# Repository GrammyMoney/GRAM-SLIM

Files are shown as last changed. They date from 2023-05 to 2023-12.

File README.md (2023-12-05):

# GRAM Slim

# Introduction 
**GRAM Slim** is a modular low-profile 21-button controller designed for Smash and FGC games. It has the standard pinout for firmwares like HayBox and Pico-Rectangle, and is also compatible with more fleshed-out FGC firmwares like GP2040-CE. With industrial design from GRAM, and PCB designed in collaboration with Quark.Works, this guide goes over a DIY-friendly approach to building the original GRAM Slim, and future guides/repos may hold remixes and modifications.

**If you would like to support the developer of this project, consider purchasing parts like buttons, PCBs, USB-C to GCC cables, and official GRAM builds at [GRAMCTRL.COM](https://www.gramctrl.com) rather than a fab house.**



Included Files
-
Included in this repo is all the files needed to get started with a simple GRAM Slim build:
- **GRAM Slim Frame .stl files**
- **Fab files for top and bottom panels**
- **Template DXF** for customizing top and bottom panels
- **GRAM 24mm keycap button .stl files**

Additional Information
-
If you want more info around GRAM builds, both open source and official builds, please join the [GRAM Digital Controllers Discord](https://discord.gg/6TuHw2r2X4) to ask questions and work with the community! I would love to see people creating new interesting designs, and building upon the initial framework.

Thanks & Acknowledgements
-
There are several people who made this project possible, either directly or indirectly.
- [Quark](https://twitter.com/quark_works), who did the PCB design on this and many other GRAM projects.
- [Bjart](https://twitter.com/bjartskular2), who developed the OFOF1 chassis, which was the initial development for a lot of the ideas explored in this build, including using PCB fabs for the panels, and the general idea of stacking two panels on a frame for the enclosure.
- My life and business partner [BRUISES](https://twitter.com/bruisesxo), who has turned GRAM into what it is today, and had incredible patience with me as I toiled away at my computer late into the night designing this thing.

# Ordering & Customization Guide
While most of these files are universal and can be used at any fab house, **JLCPCB** has become the de-facto standard for DIY box manufacturing. This is due to their hyper-affordable pricing and low minimum order quantity.

Bill of Materials
-
Per GRAM Slim, you will need (some files can be made using this repository, but I will link to places to purchase them if you would like to avoid MOQs)
- 1 x [GRAM Slim PCB](https://gramctrl.com/products/gram-slim-pcb)
- 1 x set of [Top/Bottom panels](https://gramctrl.com/products/gram-slim-aluminum-panels)
- 21 x [Kailh Choc V1 switches](https://www.moergo.com/products/kailh-choc-v1-key-switches-red-brown-white-pro-red-20-pack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) (Red, Red Pro, and Whites are all great choices)
- 21 x [PG1350 Hotswap Sockets](https://mkultra.click/kailh-hotswap-sockets)
- 21 x [GRAM 24mm Choc Keycap Buttons](https://gramctrl.com/products/gram-24mm-choc-v1-keycap-buttons)
- 1 x GRAM Slim Frame
- 7 x [M5x0.8 8mm Low-Profile Socket Head Screws](https://www.mcmaster.com/92855A507)
- 7 x [M5x0.8 Round-Base Weld Nuts](https://www.mcmaster.com/90563A680)

*Optional*
- USB-C to GCC cable for console/adapter play

Tools Needed
-
This guide assumes a level of knowledge on soldering and computer literacy. General tool requirements are:
- Soldering iron
- Solder
- USB-C to USB-A cable
- 3mm hex key/allen wrench
- Pliers
- Patience :)

The PCB
-
The PCB Fabrication files should come in the form of a *Gerber ZIP file* and *bom/cpl files* (usually in Excel spreadsheet formats).

Drag them into the "Upload Gerbers" box at JLCPCB and this page will pop up:



Here you can change the color of the PCB. Green is the fastest and cheapest from JLC, but their black PCBs look *siiiiiick*. The only setting I recommend you change is to check "**Yes**" on *Confirm Production file*. This allows for any mistakes to be ironed out by their engineers.

Towards the bottom of the page, you want to turn on the switch for **PCB ASSEMBLY**.



Make sure you are assembling the *Bottom Side* of the PCB, and make sure to set *Confirm Parts Placement* to "**Yes**". None of the advanced options need to be changed.

Upon confirming your PCB Assembly options, you'll be taken to the Assembly wizard. Clicking next will give you a location to upload the *BOM* and *CPL* files (*CPL* is referred to as *Positions* in the GRAM Slim files). Once you click through, you'll be brought to you BOM list.



This will allow you to modify parts if there's any low stock. There's a line at the bottom for CH1-CH21 with some red text. This is for assembling hotswap sockets, which is not recommended for JLC, as you have to preorder them. when you click **next**, continue by clicking *Do not place*.



The wizard looks intimidating, but good news! Since you're confirming part placement, the JLC engineers will fix any errors. Just go ahead and continue.

There you have it! Your PCB is ready to order. As of the time of this writing, a set of 5 assembled boards costs $56.07 before shipping.

The Panels
-
The process of ordering aluminum panels from JLC is similar to the PCB ordering process, but much simpler. Start by dragging the **GRAM Slim Top** Zip file into the JLC upload window. We want an aluminum PCB, 1.6mm. You can choose either white or black coating (white tends to be glossy, black is matte but a fingerprint magnet). 



Under High-spec Options, make sure to remove order number, or else they'll put an ugly serial number on the panel.

Once you save to cart, you'll see this screen:



Here you can add the **GRAM Slim Bottom** Zip file, and it will copy all your settings from the Top panel. Save to cart, and you're ready to check out with your PCBs!

*Note: JLCPCB cannot transact PCB and 3D printing orders together, so place this order, then move on to 3D printing.*

The Frame
-
The frame file is pretty self explanatory. Just go into JLC's 3D printing section, drop the STL file in, and choose your material. I recommend black Resin, but LEDO 6060 is a great, low cost alternative. The only material I recommend against is the textured Nylon options, as the tolerances between the frame and panels are extremely tight, and the texture could interfere with that. make sure the surface finish is set to *sanded*.



The Buttons
-
In the files, there are two versions. A single button for reference, and a 10x .STL file for mass printing at JLC. Each GRAM Slim requires 2.1 prints, so to make the minimum order quantity of 5 PCBs, you will need to order 11 prints of it.

The 10x file is the ideal for JLC, as it minimizes cost. JLC may reach out to you and add some cost (0.30/pc) for small parts. This is normal.

The buttons have been tested in 4 material materials:
- **LEDO 6060** (natural white, most cost-effective option, goes well with matching frame and black aluminum panels)
- **Black Resin** (matte grayish-black, goes well with both black and white panels)
- **PA12-HP Nylon** (Only slightly more expensive for buttons, but gives an amazing textured finish, very premium feel)
- **8001 Transparent Resin** (Really cool, really expensive)

# Build Guide

Building the GRAMv2 is relatively straightforward, but an updated in-depth build guide (including a video!) is currently in the works.

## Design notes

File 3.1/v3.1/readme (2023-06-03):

Adjusted footprints to be slightly easier to solder, moved traces to avoid disconnection from solder pads

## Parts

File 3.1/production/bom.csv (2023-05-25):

Designator | Footprint | Quantity | Value | LCSC Part #
C1, C10, C2, C4 | 402 | 4 | 1uF | C52923
C11, C12, C13, C14, C15, C16, C17, C3, C5, C6 | 402 | 10 | 100nF | C1525
C7, C8 | 402 | 2 | 22pF | C1555
C9 | 402 | 1 | 10uF | C15525
CH1, CH10, CH11, CH12, CH13, CH14, CH15, CH16, CH17, CH18, CH19, CH2, CH20, CH21, CH3, CH4, CH5, CH6, CH7, CH8, CH9 | SW_choc_v1_HS_1u | 21 | choc_SW_HS
D1, D2 | D_SOD-123 | 2 | Schottky Diode | C8598
D3 | 805 | 1 | GREEN | C84256
F1 | 1206 | 1 | 500 mA | C70076
J1 | TYPE-C_24P_QCHT | 1 | USB C Connector | C456013
R1 | 603 | 1 | 1M | C25190
R10, R11 | 402 | 2 | 1k | C11702
R2, R3 | 402 | 2 | 5.1k | C25744
R4 | 402 | 1 | 470 | C25117
R5 | 603 | 1 | 5.6k | C23189
R6 | 603 | 1 | 10k | C25804
R7 | 402 | 1 | 10k | C25744
R8, R9 | 603 | 2 | 27 | C25190
U1 | SOT-23 | 1 | XC6206 | C5446
U2 | SOT-23-6 | 1 | USBLC6-2SC6 | C5250994
U3 | RP2040-QFN-56 | 1 | RP2040 | C2040
U4 | SOIC-8_5.23x5.23mm_P1.27mm | 1 | W25Q128JVS | C97521
Y1 | Crystal_SMD_3225-4Pin_3.2x2.5mm | 1 | 12MHz | C9002
SW1 | SW_SPST_SKQG_WithStem | 1 | Boot | C318884

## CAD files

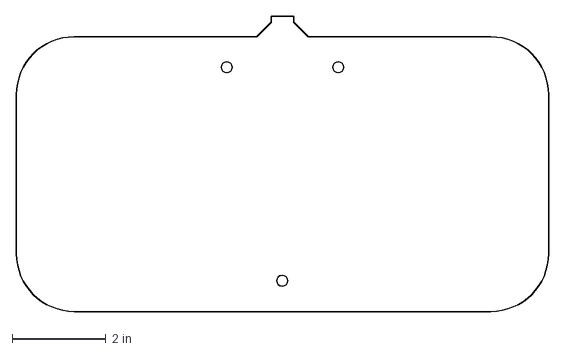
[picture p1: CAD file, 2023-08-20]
3.1/PCB OUTLINE FINAL.dxf
11.4 x 6.30 in

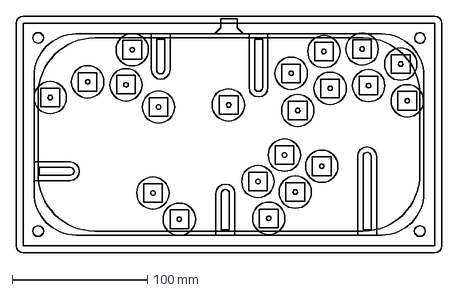
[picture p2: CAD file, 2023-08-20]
3.1/EU BOX LAYOUT 5 FINAL FOR REAL.dxf
314.8 x 175.1 mm

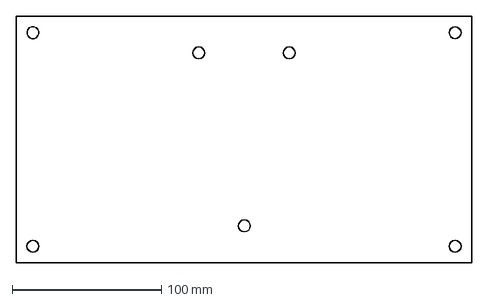
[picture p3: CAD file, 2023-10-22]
3.4/Bottom panel template.dxf
304.8 x 165.1 mm

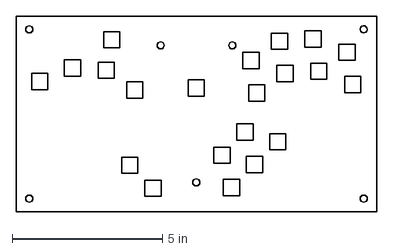
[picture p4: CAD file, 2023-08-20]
3.4/Top Panel Template.dxf
12.0 x 6.50 in

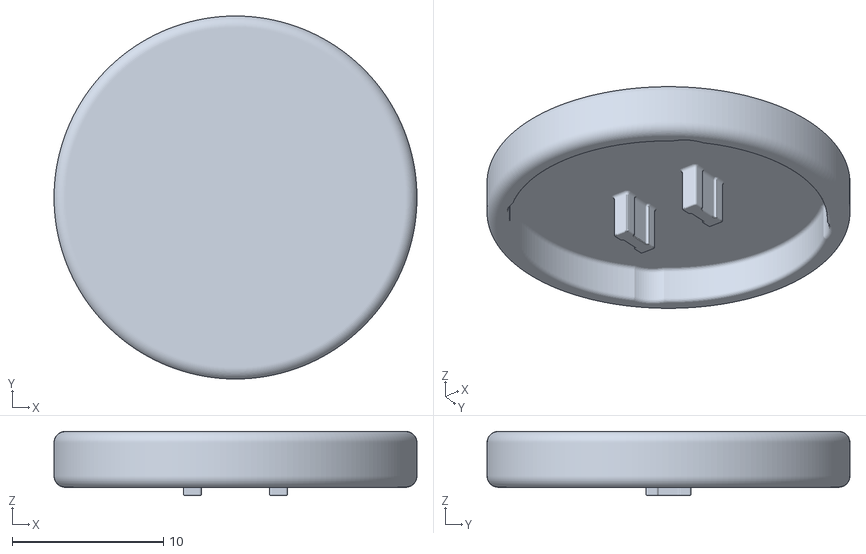
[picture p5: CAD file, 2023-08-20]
3.4/GRAM Choc 24mm.stl
24.0 x 24.0 x 4.25

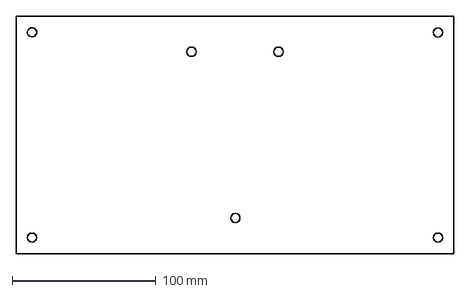
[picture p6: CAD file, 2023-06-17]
3.4/bottom outline.dxf
304.8 x 165.1 mm

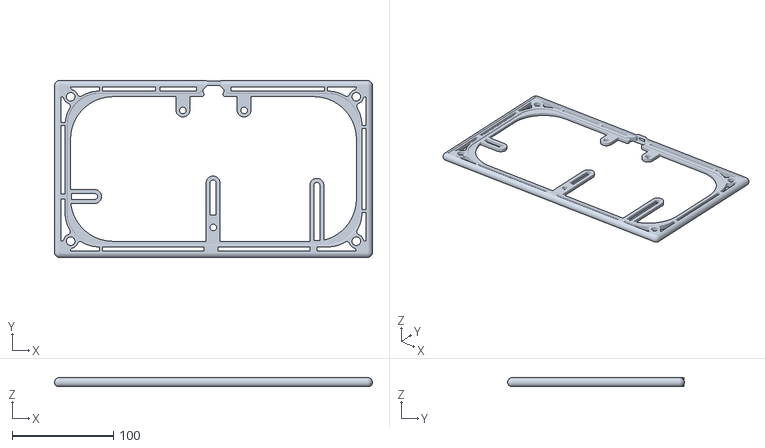
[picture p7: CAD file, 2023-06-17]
3.4/GRAM Slim Frame.stl
314.8 x 175.1 x 8.90

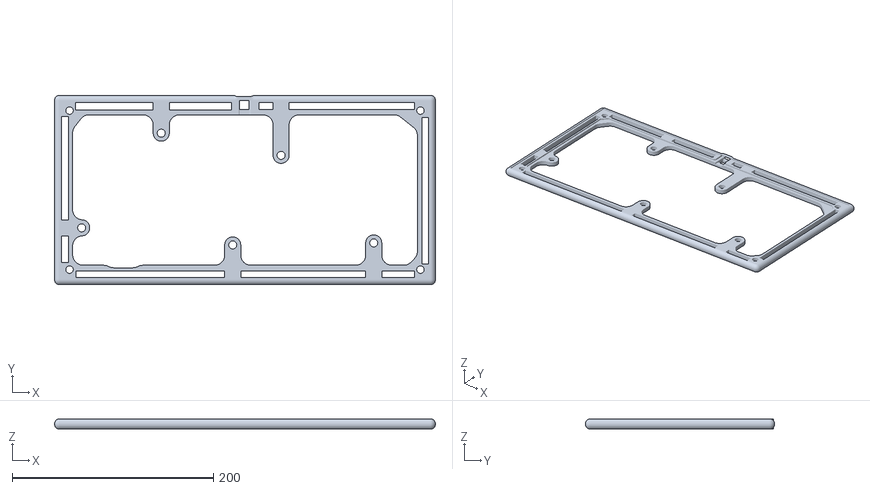
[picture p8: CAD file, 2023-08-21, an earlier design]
LEGACY (Tsunami)/GRAM Slim V2 Frame.stl
378.3 x 188.0 x 10.2

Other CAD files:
3.4/v2 buttons printable x10.stl

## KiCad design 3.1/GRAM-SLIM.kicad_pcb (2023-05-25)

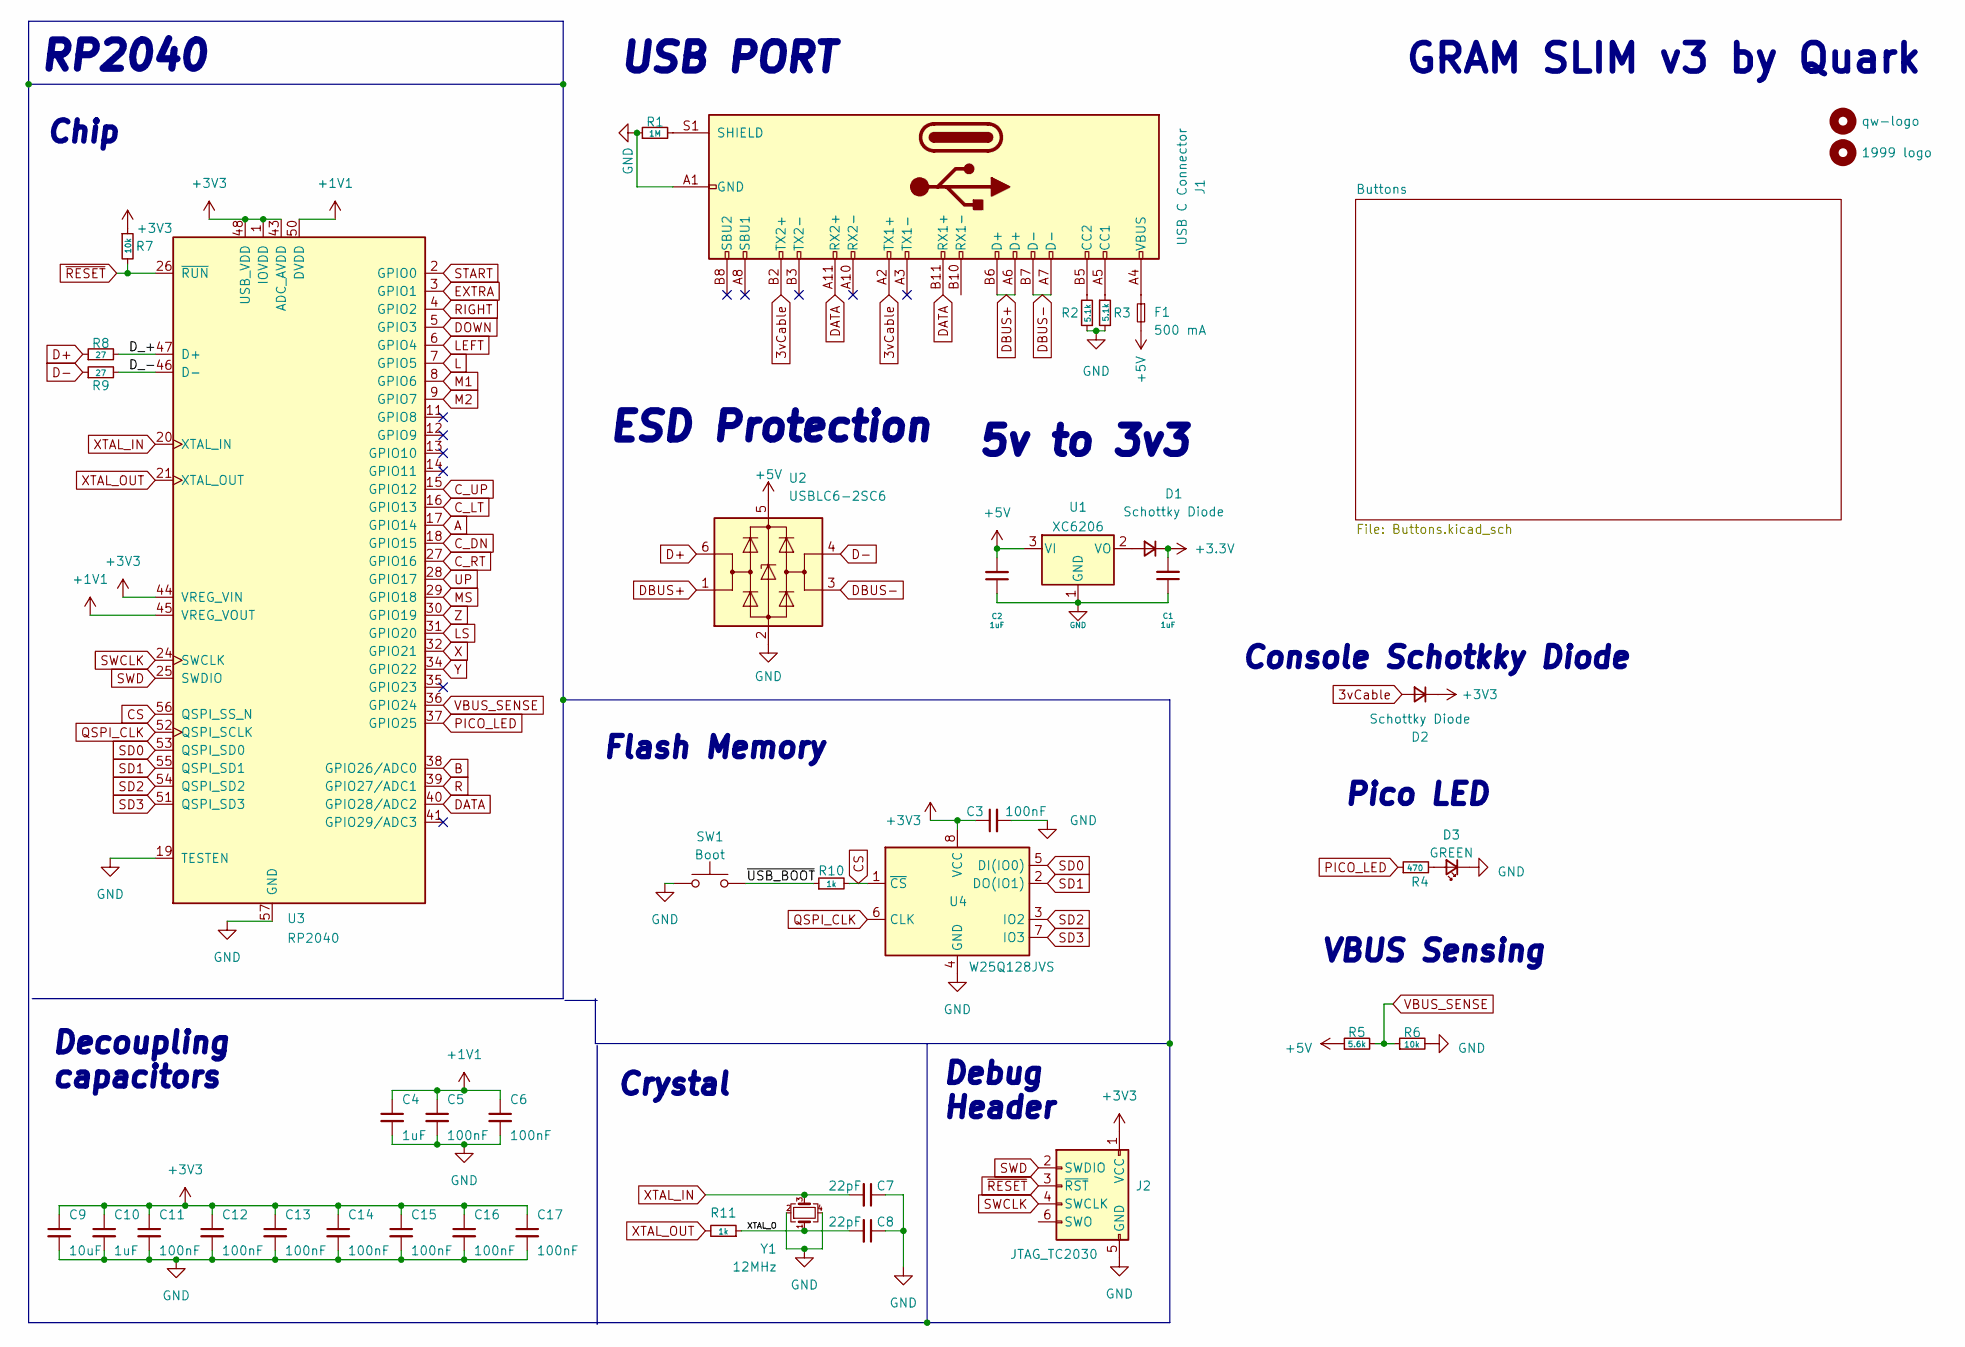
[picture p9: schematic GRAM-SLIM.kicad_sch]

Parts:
C1, C2, C4, C10: 1uF; C_0402_1005Metric; LCSC C52923
C3, C5, C6, C11, C12, C13, C14, C15, C16, C17: 100nF; C_0402_1005Metric; LCSC C1525
C7, C8: 22pF; C_0402_1005Metric; LCSC C1555
C9: 10uF; C_0402_1005Metric; LCSC C15525
D1, D2: Schottky Diode; D_SOD-123; LCSC C130880
D3: GREEN; LED_0805_2012Metric
F1: 500 mA; Fuse_1206_3216Metric
H1: qw-logo; qw new logo silk + copper md
H2: 1999 logo; 1999 logo md
J1: USB C Connector; TYPE-C_24P_QCHT; LCSC C456013
J2: JTAG_TC2030; CON_TC2030_outlined
R1: 1M; R_0603_1608Metric; LCSC C25190
R2, R3: 5.1k; R_0402_1005Metric; LCSC C25744
R4: 470; R_0402_1005Metric
R5: 5.6k; R_0603_1608Metric
R6: 10k; R_0603_1608Metric
R7: 10k; R_0402_1005Metric; LCSC C25744
R8, R9: 27; R_0603_1608Metric; LCSC C25190
R10, R11: 1k; R_0402_1005Metric; LCSC C11702
SW1: Boot; SW_SPST_SKQG_WithStem; LCSC C5156480
U1: XC6206; SOT-23; LCSC C5446
U2: USBLC6-2SC6; SOT-23-6
U3: RP2040; RP2040-QFN-56; LCSC C2040
U4: W25Q128JVS; SOIC-8_5.23x5.23mm_P1.27mm; LCSC C97521
Y1: 12MHz; Crystal_SMD_3225-4Pin_3.2x2.5mm; LCSC C9002

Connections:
3vCable: D2.2 (A), J1.A2 (TX1+), J1.B2 (TX2+)
+1V1: C4.1, C5.1, C6.1, U3.23 (DVDD), U3.45 (VREG_VOUT), U3.50 (DVDD)
+5V: C2.2, F1.2, R5.1, U1.3 (VI), U2.5 (VBUS)
/D_+: R8.2, U3.47 (D+)
/D_-: R9.2, U3.46 (D-)
/XTAL_O: C8.2, R11.1, Y1.1
/~USB_BOOT: R10.1, SW1.2
A: U3.17 (GPIO14); also elsewhere on the board
B: U3.38 (GPIO26/ADC0); also elsewhere on the board
CS: R10.2, U3.56 (QSPI_SS_N), U4.1 (~CS)
C_DN: U3.18 (GPIO15); also elsewhere on the board
C_LT: U3.16 (GPIO13); also elsewhere on the board
C_RT: U3.27 (GPIO16); also elsewhere on the board
C_UP: U3.15 (GPIO12); also elsewhere on the board
D+: R8.1, U2.6 (I/O1)
D-: R9.1, U2.4 (I/O2)
DATA: J1.A11 (RX2+), J1.B11 (RX1+), U3.40 (GPIO28/ADC2)
DBUS+: J1.A6 (D+), J1.B6 (D+), U2.1 (I/O1)
DBUS-: J1.A7 (D-), J1.B7 (D-), U2.3 (I/O2)
DOWN: U3.5 (GPIO3); also elsewhere on the board
EXTRA: U3.3 (GPIO1); also elsewhere on the board
GND: C1.1, C2.1, C3.2, C4.2, C5.2, C6.2, C7.1, C8.1, C9.2, C10.2, C11.2, C12.2, C13.2, C14.2, C15.2, C16.2, C17.2, D3.1 (K), J1.A1 (GND), J1.A12 (GND), J1.B1 (GND), J1.B12 (GND), J2.5 (GND), R1.1, R2.1, R3.2, R6.2, SW1.1, U1.1 (GND), U2.2 (GND), U3.19 (TESTEN), U3.57 (GND), U4.4 (GND), Y1.2, Y1.4; also elsewhere on the board
L: U3.7 (GPIO5); also elsewhere on the board
LEFT: U3.6 (GPIO4); also elsewhere on the board
LS: U3.31 (GPIO20); also elsewhere on the board
M1: U3.8 (GPIO6); also elsewhere on the board
M2: U3.9 (GPIO7); also elsewhere on the board
MS: U3.29 (GPIO18); also elsewhere on the board
unnamed: D1.2 (A), U1.2 (VO)
unnamed: D3.2 (A), R4.2
unnamed: F1.1, J1.A4 (VBUS), J1.A9 (VBUS), J1.B4 (VBUS), J1.B9 (VBUS)
unnamed: J1.A5 (CC1), R3.1
unnamed: J1.B5 (CC2), R2.2
unnamed: J1.S1 (SHIELD), R1.2
PICO_LED: R4.1, U3.37 (GPIO25)
QSPI_CLK: U3.52 (QSPI_SCLK), U4.6 (CLK)
R: U3.39 (GPIO27/ADC1); also elsewhere on the board
RIGHT: U3.4 (GPIO2); also elsewhere on the board
SD0: U3.53 (QSPI_SD0), U4.5 (DI(IO0))
SD1: U3.55 (QSPI_SD1), U4.2 (DO(IO1))
SD2: U3.54 (QSPI_SD2), U4.3 (IO2)
SD3: U3.51 (QSPI_SD3), U4.7 (IO3)
START: U3.2 (GPIO0); also elsewhere on the board
SWCLK: J2.4 (SWCLK), U3.24 (SWCLK)
SWD: J2.2 (SWDIO), U3.25 (SWDIO)
UP: U3.28 (GPIO17); also elsewhere on the board
VBUS_SENSE: R5.2, R6.1, U3.36 (GPIO24)
X: U3.32 (GPIO21); also elsewhere on the board
XTAL_IN: C7.2, U3.20 (XTAL_IN), Y1.3
XTAL_OUT: R11.2, U3.21 (XTAL_OUT)
Y: U3.34 (GPIO22); also elsewhere on the board
Z: U3.30 (GPIO19); also elsewhere on the board
~RESET: J2.3 (~RST), R7.2, U3.26 (~RUN)

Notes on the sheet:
GRAM SLIM v3 by Quark
Flash Memory
5v to 3v3
Pico LED
Crystal
Chip
Console Schotkky Diode
RP2040
VBUS Sensing
Debug Header
USB PORT
ESD Protection
Decoupling capacitors

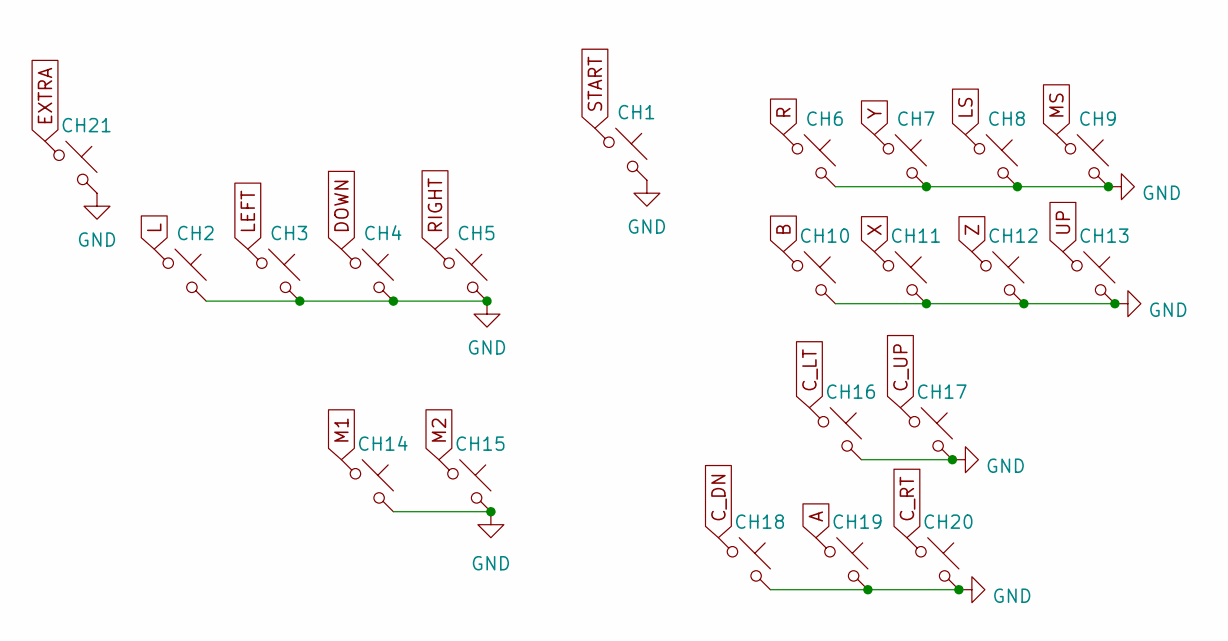
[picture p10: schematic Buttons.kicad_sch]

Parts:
CH1, CH2, CH3, CH4, CH5, CH6, CH7, CH8, CH9, CH10, CH11, CH12, CH13, CH14, CH15, CH16, CH17, CH18, CH19, CH20, CH21: choc_SW_HS; SW_choc_v1_HS_1u

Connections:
A: CH19.1; also elsewhere on the board
B: CH10.1; also elsewhere on the board
C_DN: CH18.1; also elsewhere on the board
C_LT: CH16.1; also elsewhere on the board
C_RT: CH20.1; also elsewhere on the board
C_UP: CH17.1; also elsewhere on the board
DOWN: CH4.1; also elsewhere on the board
EXTRA: CH21.1; also elsewhere on the board
GND: CH1.2, CH2.2, CH3.2, CH4.2, CH5.2, CH6.2, CH7.2, CH8.2, CH9.2, CH10.2, CH11.2, CH12.2, CH13.2, CH14.2, CH15.2, CH16.2, CH17.2, CH18.2, CH19.2, CH20.2, CH21.2; also elsewhere on the board
L: CH2.1; also elsewhere on the board
LEFT: CH3.1; also elsewhere on the board
LS: CH8.1; also elsewhere on the board
M1: CH14.1; also elsewhere on the board
M2: CH15.1; also elsewhere on the board
MS: CH9.1; also elsewhere on the board
R: CH6.1; also elsewhere on the board
RIGHT: CH5.1; also elsewhere on the board
START: CH1.1; also elsewhere on the board
UP: CH13.1; also elsewhere on the board
X: CH11.1; also elsewhere on the board
Y: CH7.1; also elsewhere on the board
Z: CH12.1; also elsewhere on the board

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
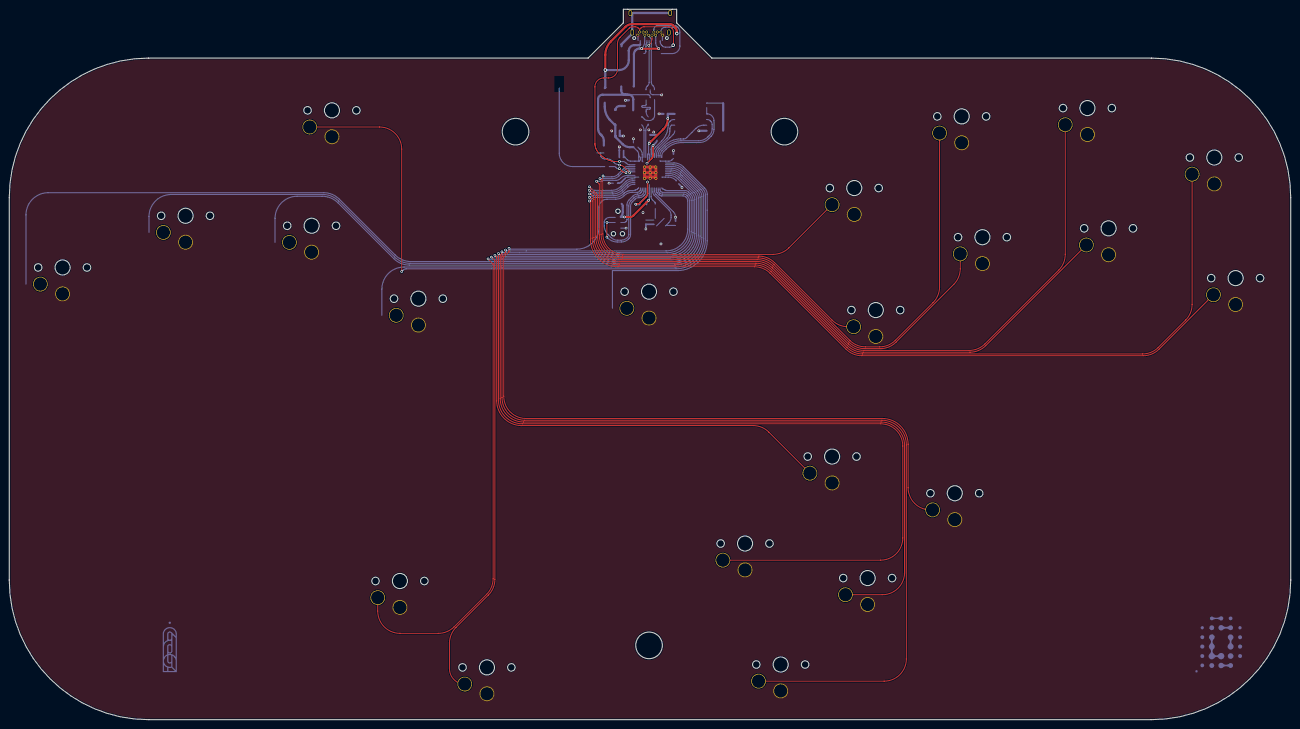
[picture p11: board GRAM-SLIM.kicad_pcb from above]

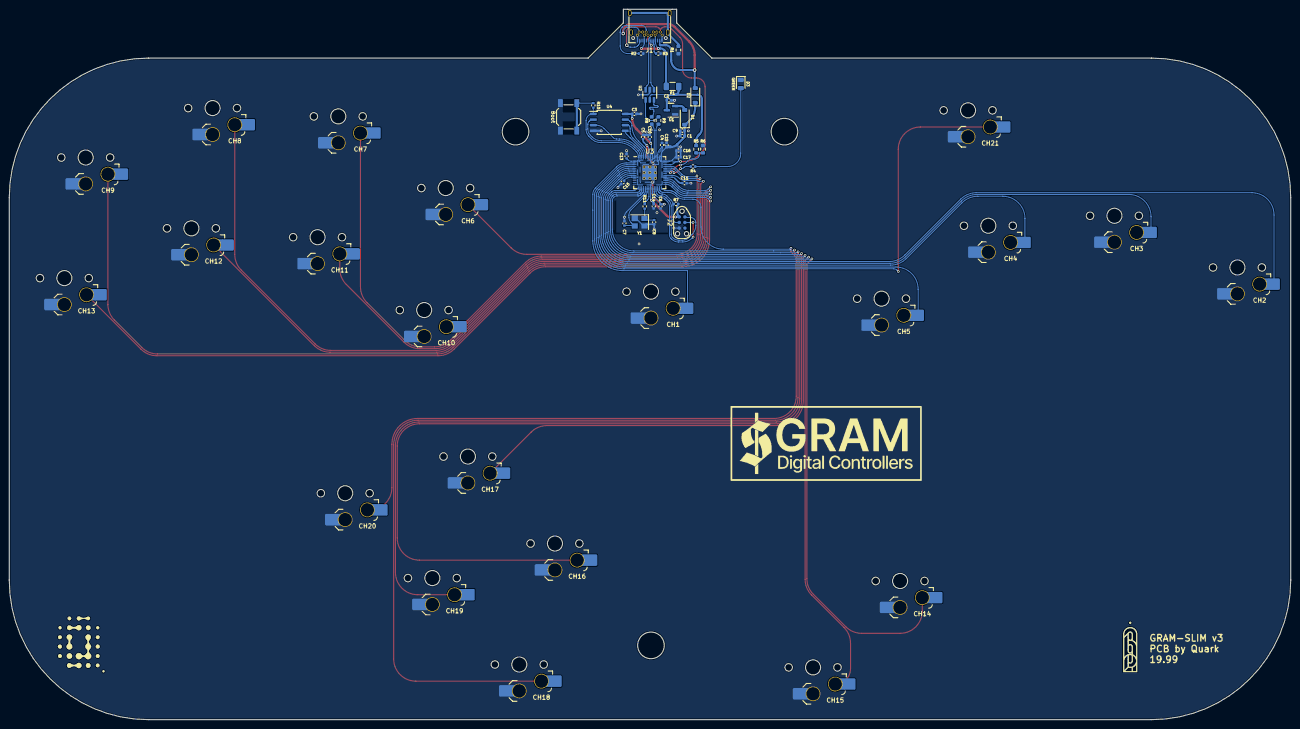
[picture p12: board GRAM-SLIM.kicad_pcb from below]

Board: 2 copper layers, 288.8 x 160.1 mm, 63 parts (63 on the bottom side), 54 nets.

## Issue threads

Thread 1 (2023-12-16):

Add pre-sliced files for the frame in order to achieve comptaibility with most 3D printers

matru, 2023-12-16:
Would be cool if we can have pre-sliced files for the frame, of course with some modification to enable effective gluing together or something else. Most printers, don't go beyond 25x25x25 cm and most printers are smaller than this. So it's impossible to print at home, and printing them with JLC is pretty expensive.

I would've have done this myself, but sadly I have no experience with 3D modeling. :(

GrammyMoney, 2023-12-17:
Printing the frame is pretty difficult; perhaps a redesigned FDM-optimized option? Might get to work on this; most slicers have a built-in "cut" feature, which should be more than enough if you want to print the original STL or STEP files!

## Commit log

2023-05-25 Added PCB with integrated RP2040
    [Buttons.kicad_sch, GRAM-SLIM.kicad_pcb, GRAM-SLIM.kicad_sch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]
2023-06-03 Added v3.1 files
    [Buttons.kicad_sch, GRAM-SLIM.kicad_pcb, GRAM-SLIM.kicad_sch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]
2023-06-17 added v3.4
    [Buttons.kicad_sch, GRAM-SLIM.kicad_pcb, GRAM-SLIM.kicad_sch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]
2023-08-20 Prepared for public release
    LETS GOOOOOO
    [Buttons.kicad_sch, EU BOX LAYOUT 5 FINAL FOR REAL.dxf, GRAM Choc 24mm.stl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]
2023-08-20 Added DXF templates for faceplates
    [Bottom panel template.dxf, Top Panel Template.dxf]
2023-08-20 added gerbers for PCB
2023-08-21 Added Tsunami
    [GRAM Slim V2 Frame.stl]
2023-10-22 Updated Panel Files for Clarity
    [Bottom panel template.dxf, TOP PANELS.kicad_pcb, TOP PANELS.kicad_sch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]
2023-10-22 removed punctuation for JLC
    [GRAM Slim Frame.stl]
2023-12-18 added better buttons
2023-12-18 Rename v17 basically v2 buttons x10.stl to v2 buttons printable x10.stl
    [v2 buttons printable x10.stl]
2023-12-18 moved STL
    [v2 buttons printable x10.stl]
